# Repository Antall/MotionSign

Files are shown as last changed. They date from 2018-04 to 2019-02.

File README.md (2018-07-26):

View this project on [CADLAB.io](https://cadlab.io/node/895). 

# MotionSign
Controls sign activated by motion sensor.

# Setup

## Setting up Arduino and Compiling the Code (MAC)

1. Clone this repo to `~/Documents/Arduino` with `cd ~/Documents/Arduino && git clone git@github.com:bguest/MotionSign.git`
2. Change directory to MotionSign with `cd MotionSign`
3. Mod setup script `chmod +x setup.sh`
4. Run Setup `.\setup.sh` this will clone correct versions of `Adafruit_WS2801`
5. Download Arduino
6. Launch Arduino
7. Open MotionSign328
8. Set board to `Arduino HUZZAH ESP8266`
9. Set cpu frequency to `80MHz`
10. Set upload speed to `115200`
10. Verify and Upload Code

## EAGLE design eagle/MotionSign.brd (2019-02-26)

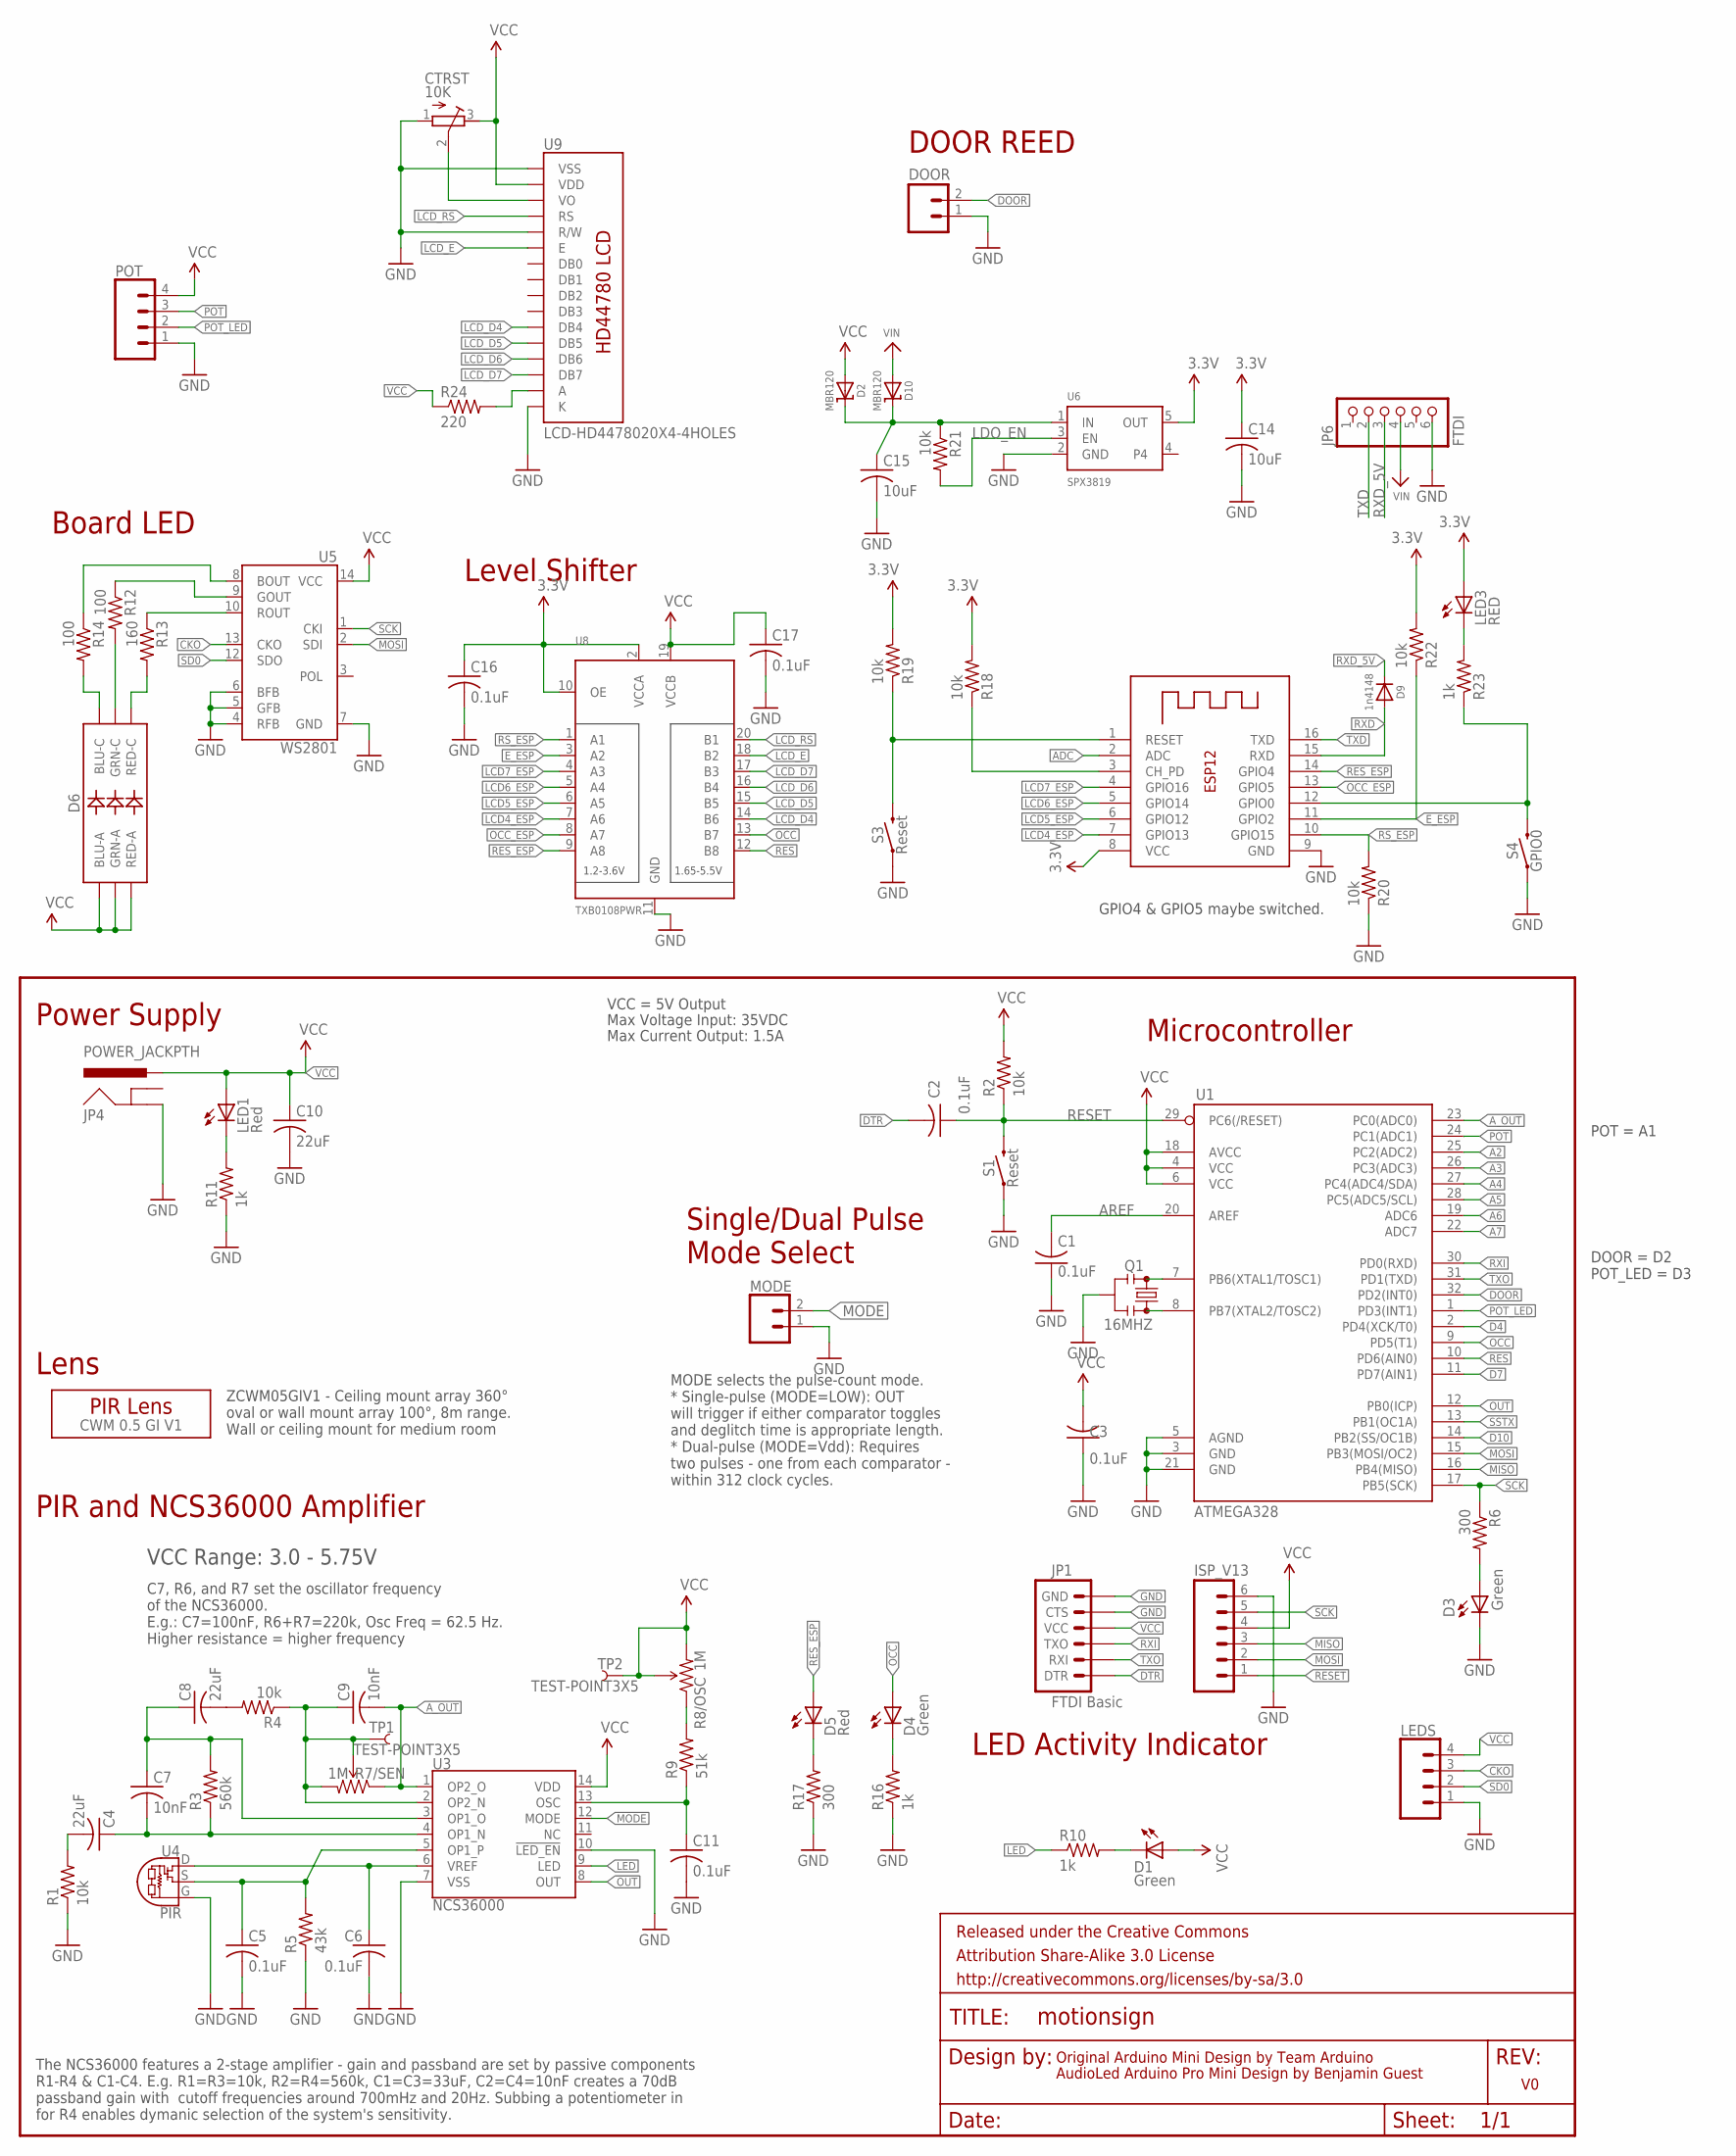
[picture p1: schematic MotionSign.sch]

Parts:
C1, C2, C3, C5, C6, C11, C16, C17: 0.1uF; C0805
C4, C8, C10: 22uF; C0805
C7, C9: 10nF; C0805
C14, C15: 10uF; C0805
CTRST: 10K; RTRIM3296W
D1, D3, D4: Green; CHIPLED_0805
D2, D10: MBR120; SOD-123
D5: Red; CHIPLED_0805
D6: LED-RGBNO_IC; LED-TRICOLOR-5050
D9: 1n4148; SOD-323
DOOR: CONN_02JST-PTH-2; JST-2-PTH
FRAME1: FRAME-LETTER; CREATIVE_COMMONS
ISP_V13: M06SIP; 1X06
JP1: FTDI Basic; 1X06
JP4: POWER_JACKPTH; POWER_JACK_PTH
JP6: FTDI; 1X06_ROUND_70
LED1: Red; CHIPLED_0805
LED3: RED; CHIP-LED0805
LEDS: CONN_04JST-PTH; JST-4-PTH
MODE: CONN_02; 1X02
POT: CONN_04JST-PTH; JST-4-PTH
Q1: 16MHZ; RESONATOR-SMD
R1, R2, R4, R18, R19, R20, R21, R22: 10k; M0805
R3: 560k; M0805
R5: 43k; M0805
R6, R17: 300; M0805
R7/SEN, R8/OSC: 1M; TRIMPOT-TC33X
R9: 51k; M0805
R10, R11, R16, R23: 1k; M0805
R12, R14: 100; M0805
R13: 160; M0805
R24: 220; 0204/7
S1, S3: Reset; TACTILE_SWITCH_SMD_5.2MM
S4: GPIO0; TACTILE_SWITCH_SMD_5.2MM
TP1, TP2: TEST-POINT3X5; PAD.03X.05
U1: ATMEGA328; TQFP32-08
U3: NCS36000; SO14
U4: PIR
U5: WS2801; SOP-14
U6: SPX3819; SOT23-5
U8: TXB0108PWR; TSSOP20
U9: LCD-HD4478020X4-4HOLES; LCD-20X4-1HOLE_NOSILK
U$1: CWM 0.5 GI V1; LENS-CWM-0.5-GI-V1
X2: ESP-12

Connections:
3.3V: C14.1, C16.1, LED3.A, R18.2, R19.2, R22.2, U6.5 (OUT), U8.2 (VCCA), U8.10 (OE), X2.8 (VCC)
A2: U1.25 (PC2(ADC2))
A3: U1.26 (PC3(ADC3))
A4: U1.27 (PC4(ADC4/SDA))
A5: U1.28 (PC5(ADC5/SCL))
A6: U1.19 (ADC6)
A7: U1.22 (ADC7)
ADC: X2.2 (ADC)
AREF: C1.2, U1.20 (AREF)
A_OUT: C9.2, R7/SEN.1 (CCW), U1.23 (PC0(ADC0)), U3.1 (OP2_O)
CH_PD: R18.1, X2.3 (CH_PD)
CKO: LEDS.3, U5.13 (CKO)
D4: U1.2 (PD4(XCK/T0))
D7: U1.11 (PD7(AIN1))
D10: U1.14 (PB2(SS/OC1B))
DOOR: DOOR.2, U1.32 (PD2(INT0))
DTR: C2.2, JP1.1 (DTR)
E_ESP: R22.1, U8.3 (A2), X2.11 (GPIO2)
GND: C1.1, C3.1, C5.2, C6.2, C10.2, C11.2, C14.2, C15.2, C16.2, C17.2, CTRST.1 (A), D3.C, DOOR.1, ISP_V13.6, JP1.5 (CTS), JP1.6 (GND), JP4.GND, JP6.6, LEDS.1, MODE.1, POT.1, Q1.2, R1.1, R5.1, R11.1, R16.1, R17.1, R20.1, S1.1, S1.2 (1), S3.1, S3.2 (1), S4.1, S4.2 (1), U1.3 (GND), U1.5 (AGND), U1.21 (GND), U3.7 (VSS), U3.10 (!LED_EN!), U4.G, U5.4 (RFB), U5.5 (GFB), U5.6 (BFB), U5.7 (GND), U6.2 (GND), U8.11 (GND), U9.P$1 (VSS), U9.P$5 (R/W), U9.P$16 (K), X2.9 (GND)
GPIO0: R23.1, S4.3 (2), S4.4 (2), X2.12 (GPIO0)
LCD4_ESP: U8.7 (A6), X2.7 (GPIO13)
LCD5_ESP: U8.6 (A5), X2.6 (GPIO12)
LCD6_ESP: U8.5 (A4), X2.5 (GPIO14)
LCD7_ESP: U8.4 (A3), X2.4 (GPIO16)
LCD_D4: U8.14 (B6), U9.P$11 (DB4)
LCD_D5: U8.15 (B5), U9.P$12 (DB5)
LCD_D6: U8.16 (B4), U9.P$13 (DB6)
LCD_D7: U8.17 (B3), U9.P$14 (DB7)
LCD_E: U8.18 (B2), U9.P$6 (E)
LCD_RS: U8.20 (B1), U9.P$4 (RS)
LDO_EN: R21.2, U6.3 (EN)
LED: R10.1, U3.9 (LED)
MISO: ISP_V13.3, U1.16 (PB4(MISO))
MODE: MODE.2, U3.12 (MODE)
MOSI: ISP_V13.2, U1.15 (PB3(MOSI/OC2)), U5.2 (SDI)
unnamed: Q1.3, U1.8 (PB7(XTAL2/TOSC2))
unnamed: Q1.1, U1.7 (PB6(XTAL1/TOSC1))
unnamed: C6.1, U3.6 (VREF), U4.D
unnamed: LED1.C, R11.2
unnamed: C5.1, R5.2, U3.5 (OP1_P), U4.S
unnamed: C4.2, R1.2
unnamed: D3.A, R6.2
unnamed: C8.2, R4.2
unnamed: C4.1, C7.2, R3.1, U3.4 (OP1_N)
unnamed: C7.1, C8.1, R3.2, U3.3 (OP1_O)
unnamed: C9.1, R4.1, R7/SEN.2 (WIPER), R7/SEN.3 (CW), TP1.P$1, U3.2 (OP2_N)
unnamed: C11.1, R9.1, U3.13 (OSC)
unnamed: R8/OSC.1 (CCW), R9.2
unnamed: D1.C, R10.2
unnamed: R14.1, U5.8 (BOUT)
unnamed: R13.1, U5.10 (ROUT)
unnamed: LED3.C, R23.2
unnamed: D5.C, R17.2
unnamed: R12.1, U5.9 (GOUT)
unnamed: D6.4 (BLU-C), R14.2
unnamed: D6.6 (GRN-C), R12.2
unnamed: D6.5 (RED-C), R13.2
unnamed: C15.1, D2.C, D10.C, R21.1, U6.1 (IN)
unnamed: D4.C, R16.2
unnamed: R24.2, U9.P$15 (A)
OCC: D4.A, U1.9 (PD5(T1)), U8.13 (B7)
OCC_ESP: U8.8 (A7), X2.13 (GPIO5)
OUT: U1.12 (PB0(ICP)), U3.8 (OUT)
POT: POT.3, U1.24 (PC1(ADC1))
POT_LED: POT.2, U1.1 (PD3(INT1))
RES: U1.10 (PD6(AIN0)), U8.12 (B8)
RESET: C2.1, ISP_V13.1, R2.1, S1.3 (2), S1.4 (2), U1.29 (PC6(/RESET))
RESET_HZA: R19.1, S3.3 (2), S3.4 (2), X2.1 (RESET)
RES_ESP: D5.A, U8.9 (A8), X2.14 (GPIO4)
RS_ESP: R20.2, U8.1 (A1), X2.10 (GPIO15)
RXD: D9.A, X2.15 (RXD)
RXD_5V: D9.C, JP6.3
RXI: JP1.3 (TXO), U1.30 (PD0(RXD))
SCK: ISP_V13.5, R6.1, U1.17 (PB5(SCK)), U5.1 (CKI)
SD0: LEDS.2, U5.12 (SDO)
SSTX: U1.13 (PB1(OC1A))
TXD: JP6.2, X2.16 (TXD)
TXO: JP1.2 (RXI), U1.31 (PD1(TXD))
VCC: C3.2, C10.1, C17.1, CTRST.3 (E), D1.A, D2.A, D6.1 (GRN-A), D6.2 (RED-A), D6.3 (BLU-A), ISP_V13.4, JP1.4 (VCC), JP4.PWR, LED1.A, LEDS.4, POT.4, R2.2, R8/OSC.2 (WIPER), R8/OSC.3 (CW), R24.1, TP2.P$1, U1.4 (VCC), U1.6 (VCC), U1.18 (AVCC), U3.14 (VDD), U5.14 (VCC), U8.19 (VCCB), U9.P$2 (VDD)
VIN: D10.A, JP6.4
VO: CTRST.2 (S), U9.P$3 (VO)

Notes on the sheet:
Original Arduino Mini Design by Team Arduino
AudioLed Arduino Pro Mini Design by Benjamin Guest
Max Voltage Input: 35VDC
Max Current Output: 1.5A
VCC = 5V Output
VCC Range: 3.0 - 5.75V
The NCS36000 features a 2-stage amplifier - gain and passband are set by passive components R1-R4 & C1-C4. E.g. R1=R3=10k, R2=R4=560k, C1=C3=33uF, C2=C4=10nF creates a 70dB passband gain with cutoff frequencies around 700mHz and 20Hz. Subbing a potentiometer in for R4 enables dymanic selection of t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
C7, R6, and R7 set the oscillator frequency of the NCS36000. E.g.: C7=100nF, R6+R7=220k, Osc Freq = 62.5 Hz. Higher resistance = higher frequency
PIR and NCS36000 Amplifier
ZCWM05GIV1 - Ceiling mount array 360° oval or wall mount array 100°, 8m range. Wall or ceiling mount for medium room
Lens
MODE selects the pulse-count mode. * Single-pulse (MODE=LOW): OUT will trigger if either comparator toggles and deglitch time is appropriate length. * Dual-pulse (MODE=Vdd): Requires two pulses - one from each comparator - within 312 clock cycles.
Single/Dual Pulse Mode Select
LED Activity Indicator
Power Supply
Microcontroller
Board LED
Level Shifter
GPIO4 & GPIO5 maybe switched.
DOOR REED
DOOR = D2 POT_LED = D3
POT = A1

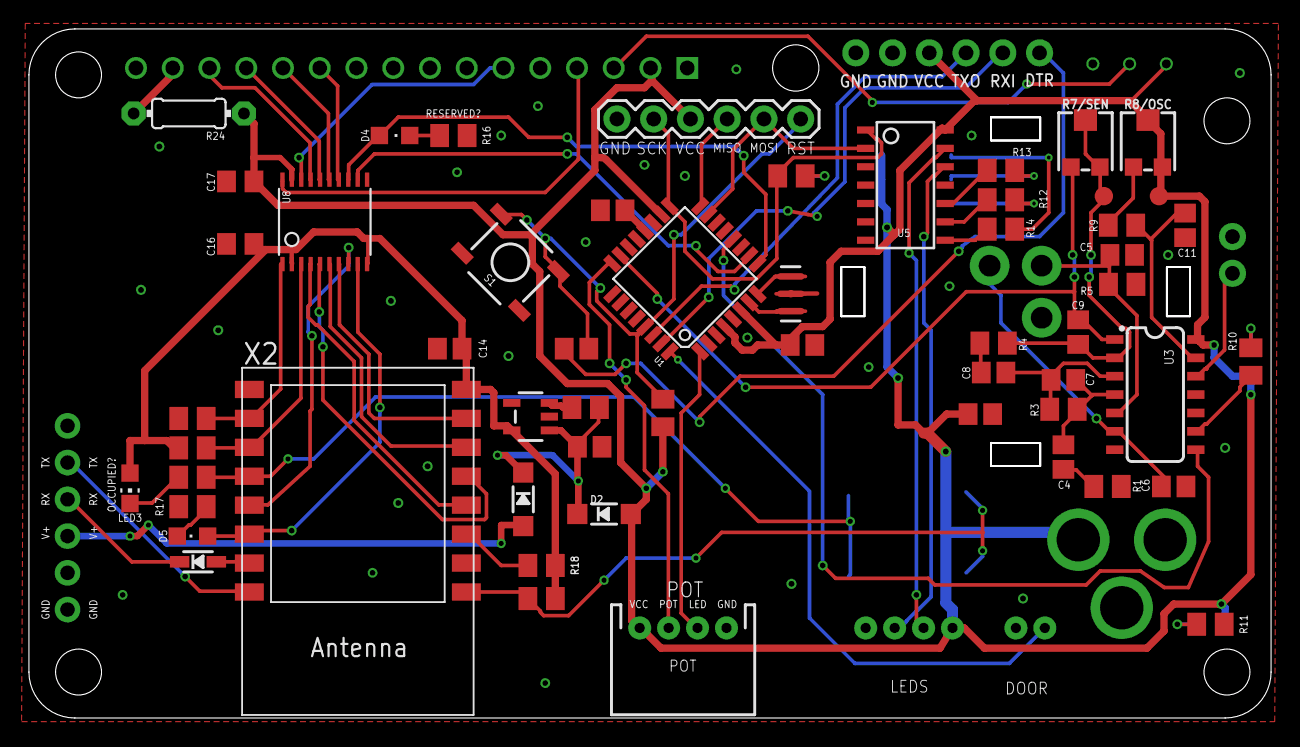
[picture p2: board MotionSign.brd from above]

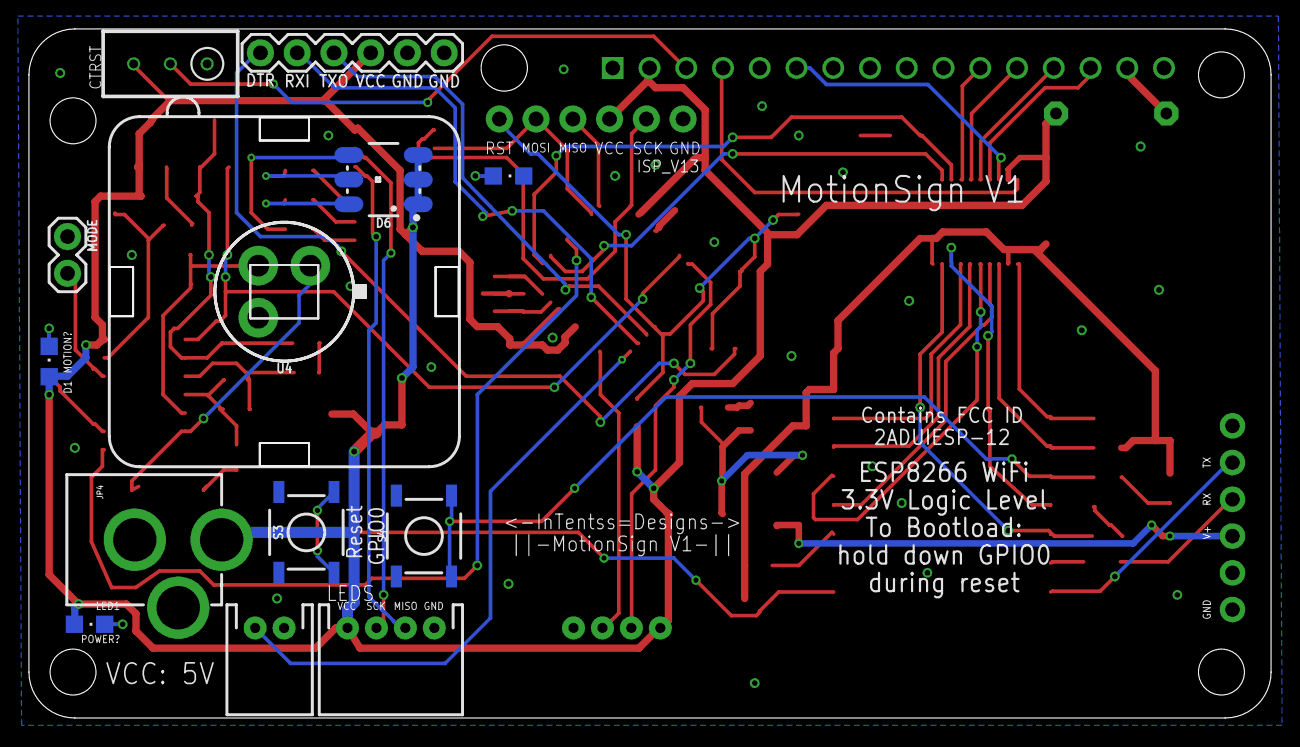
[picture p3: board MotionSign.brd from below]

Board: 2 copper layers, 85.9 x 47.6 mm, 73 parts (15 on the bottom side), 70 nets.

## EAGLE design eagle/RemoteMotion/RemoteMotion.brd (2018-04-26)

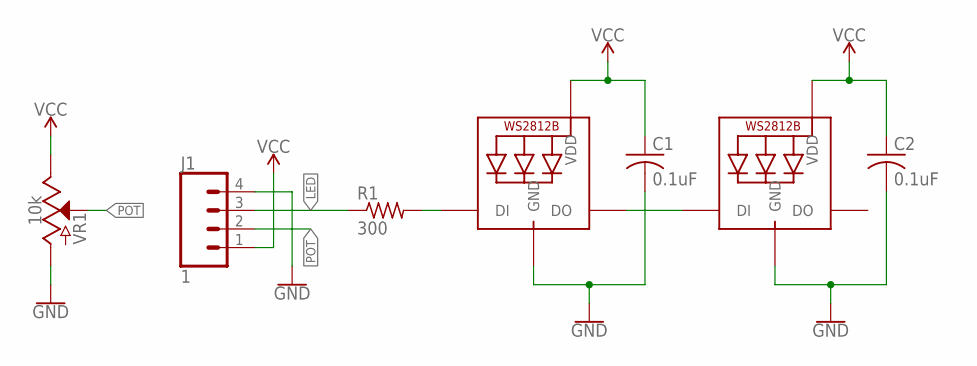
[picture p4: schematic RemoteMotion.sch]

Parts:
C1, C2: 0.1uF; C0805
J1: 1; JST-4-PTH
LED1, LED2: WS2812B5050; WS2812B
R1: 300; R0805
VR1: 10k; SLIDER-XLARGE

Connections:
GND: C1.2, C2.2, J1.4, LED1.3-GND (GND), LED2.3-GND (GND), VR1.3 (A)
LED: J1.3, R1.1
unnamed: LED1.4-DIN (DI), R1.2
unnamed: LED1.2-DOUT (DO), LED2.4-DIN (DI)
POT: J1.2, VR1.2A (S)
VCC: C1.1, C2.1, J1.1, LED1.1-VDD (VDD), LED2.1-VDD (VDD), VR1.1 (E)

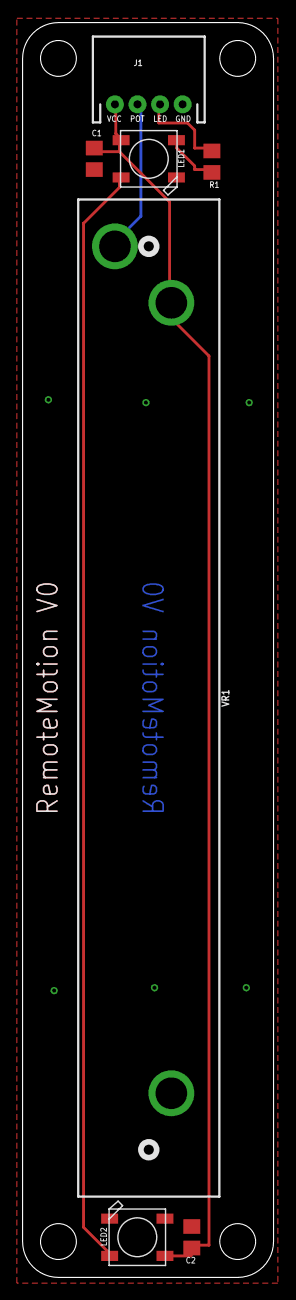
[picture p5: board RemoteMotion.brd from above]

Board: 2 copper layers, 22.2 x 111.1 mm, 7 parts (0 on the bottom side), 6 nets.

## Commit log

2018-03-25 Add Eagle
    [OfficeSign.brd, OfficeSign.sch]
2018-03-25 Move Files Around
    [OfficeSign.brd, OfficeSign.sch]
2018-03-30 Moves and Shakes
    [OfficeSign.brd, OfficeSign.sch]
2018-04-03 Add Indicator
    [OfficeSign.brd, OfficeSign.sch]
2018-04-12 Add Remote Motion / Work on Dispaly
    [OfficeSign.brd, OfficeSign.sch, RemoteMotion.brd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]
2018-04-13 Add Display / Add Indicator LEDs
    [OfficeSign.brd, OfficeSign.sch]
2018-04-13 Screen is plugged in but doesnt work
    [OfficeSign.brd, OfficeSign.sch]
2018-04-16 Display now working, removed debug prints
2018-04-17 Work on Board
    [MotionSign.brd, MotionSign.sch, OfficeSign.brd]
2018-04-18 V0 of board
    [MotionSign.brd, MotionSign.sch]
2018-04-18 Slight board improvemnents
    [MotionSign.brd]
2018-04-25 Move to managed libarary for 3d parts
    [RemoteMotion.brd, RemoteMotion.sch]
2018-04-26 More 3D parts
    [RemoteMotion.brd, RemoteMotion.sch]
2018-05-02 Move labels around vias
    [MotionSign.brd]
2018-05-09 POT Cable Labels Were Backwards
    [MotionSign.brd]
2018-05-10 Set Pot led count to 2
2018-05-10 Fix board issues
    [MotionSign.brd, MotionSign.sch]
2018-05-12 Switch GPIO4/GPIO5 pins
    [MotionSign.sch]
2018-05-16 Add 5V jumper
    [MotionSign.brd, MotionSign.sch]
2018-05-17 Switch to Managed Libary for MotionSign
    [MotionSign.brd, MotionSign.sch]
2018-05-22 Updates to Motion sign + FTDI_Extender
    [FTDI_Extender.brd, FTDI_Extender.sch, MotionSign.brd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]
2018-05-23 Additions to FTDI_Extender
    [FTDI_Extender.brd, FTDI_Extender.sch]
2018-06-12 Swap out power managment resistor with 204/7 for
    Allow for further experimentation with power managment
    [MotionSign.brd, MotionSign.sch]
2018-06-15 Add Sensitivity/Ossilation Names
    [MotionSign.brd, MotionSign.sch]
2018-06-19 switch to 60s per request remove post occupied
2018-06-20 Print Mac Address
2018-07-19 Make motion sensor more sensitive
2019-02-26 Add door reed switch
    [MotionSign.brd, MotionSign.sch]

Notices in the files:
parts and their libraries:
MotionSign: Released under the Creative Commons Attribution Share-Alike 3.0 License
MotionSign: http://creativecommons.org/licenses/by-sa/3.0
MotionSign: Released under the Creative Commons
